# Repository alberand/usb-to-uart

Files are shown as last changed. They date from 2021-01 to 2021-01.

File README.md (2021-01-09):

# USB-C UART Converter based on CH330

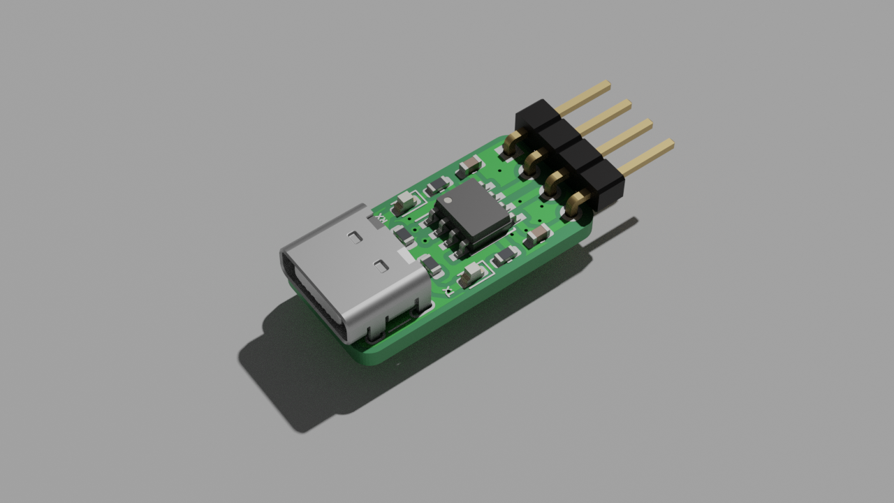
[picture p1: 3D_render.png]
3D Render of the board
[][2]

CH330 is crystal-less, <$0.35 USB UART converter in a SOIC-8 package. The CH330N
enumerates as CH340 or CH341 and its transfer speed goes up to ~2Mb/s.

Initially based on [Jan Henrik's prototype board][1]

## BOM

| Reference |  Value |  Mfr. Part |  Price |
| --- | --- | --- | --- |
| U1 | CH330N | CH330N | US$ 0.5518 |
| C2, C2 | 100n | CC0603KRX7R9BB104 | US$ 0.175 for 50 |
| D1, D2 | LED | 19-217/R6C-AL1M2VY/3T | US$ 0.282 for 20 |
| R1, R2 | 220 | 0603WAF2200T5E | US$ 0.12 for 100 |
| R3, R4 | 5.1k | 0603WAJ0512T5E | US$ 0.12 for 100 |
| P1 | USB_C_Plug_USB2.0 | U262-161N-4BVC11 | US$ 0.32 |
| J2 | | | |
| PCB | | | US$ 20 for 5 with shipping |

[1]: https://github.com/Jan--Henrik/CH330_Hardware
[2]: https://cloud.cadexchanger.com/app/viewer/5ff9c5427970d5002759ed40

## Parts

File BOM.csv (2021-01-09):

Reference | Value | Footprint | Datasheet | Mfr. Part
U1 | CH330N | Package_SO:SOIC-8_3.9x4.9mm_P1.27mm | https://datasheet.lcsc.com/szlcsc/2008191734_WCH-Jiangsu-Qin-Heng-CH330N_C108996.pdf | CH330N
C2 | 100n | Capacitor_SMD:C_0603_1608Metric | https://datasheet.lcsc.com/szlcsc/YAGEO-CC0603KRX7R9BB104_C14663.pdf | CC0603KRX7R9BB104
C1 | 100n | Capacitor_SMD:C_0603_1608Metric | https://datasheet.lcsc.com/szlcsc/YAGEO-CC0603KRX7R9BB104_C14663.pdf | CC0603KRX7R9BB104
D1 | LED | LED_SMD:LED_0603_1608Metric | https://datasheet.lcsc.com/szlcsc/Everlight-Elec-19-217-R6C-AL1M2VY-3T_C72044.pdf | 19-217/R6C-AL1M2VY/3T
R1 | 220 | Resistor_SMD:R_0603_1608Metric | https://datasheet.lcsc.com/szlcsc/Uniroyal-Elec-0603WAF2200T5E_C22962.pdf | 0603WAF2200T5E
R2 | 220 | Resistor_SMD:R_0603_1608Metric | https://datasheet.lcsc.com/szlcsc/Uniroyal-Elec-0603WAF2200T5E_C22962.pdf | 0603WAF2200T5E
J2 | Conn_01x04_Female | Connector_PinHeader_2.54mm:PinHeader_1x04_P2.54mm_Vertical | ~
P1 | USB_C_Plug_USB2.0 | Connector_USB:USB_C_Receptacle_XKB_U262-16XN-4BVC11 | https://datasheet.lcsc.com/szlcsc/2002271811_XKB-Connectivity-U262-161N-4BVC11_C319148.pdf | U262-161N-4BVC11
D2 | LED | LED_SMD:LED_0603_1608Metric | https://datasheet.lcsc.com/szlcsc/Everlight-Elec-19-217-R6C-AL1M2VY-3T_C72044.pdf | 19-217/R6C-AL1M2VY/3T
R3 | 5.1k | Resistor_SMD:R_0603_1608Metric | https://datasheet.lcsc.com/szlcsc/Uniroyal-Elec-0603WAJ0512T5E_C26000.pdf | 0603WAJ0512T5E
R4 | 5.1k | Resistor_SMD:R_0603_1608Metric | https://datasheet.lcsc.com/szlcsc/Uniroyal-Elec-0603WAJ0512T5E_C26000.pdf | 0603WAJ0512T5E

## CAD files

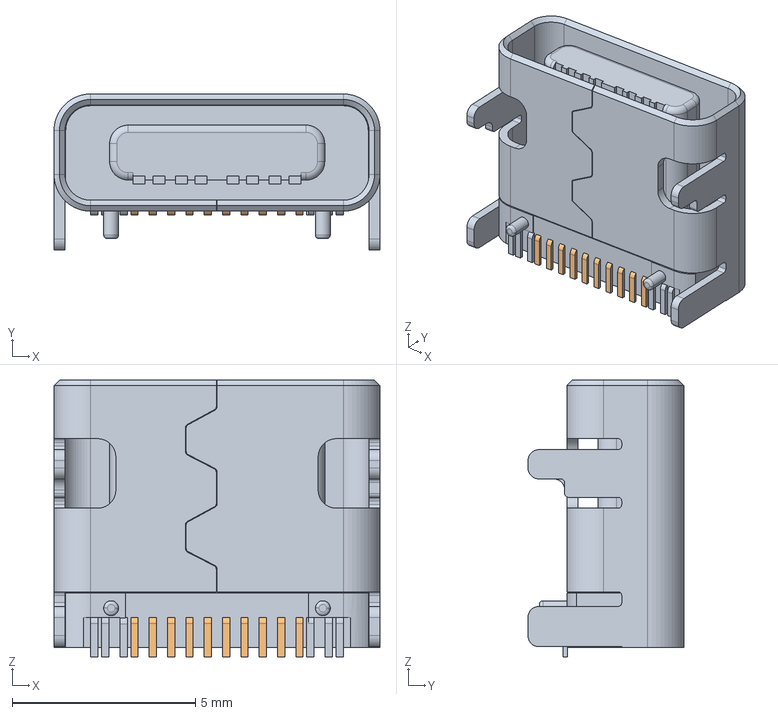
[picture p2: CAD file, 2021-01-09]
3dmodels/u262-16xn-4bvc11.stp
8.90 x 4.26 x 7.56 mm

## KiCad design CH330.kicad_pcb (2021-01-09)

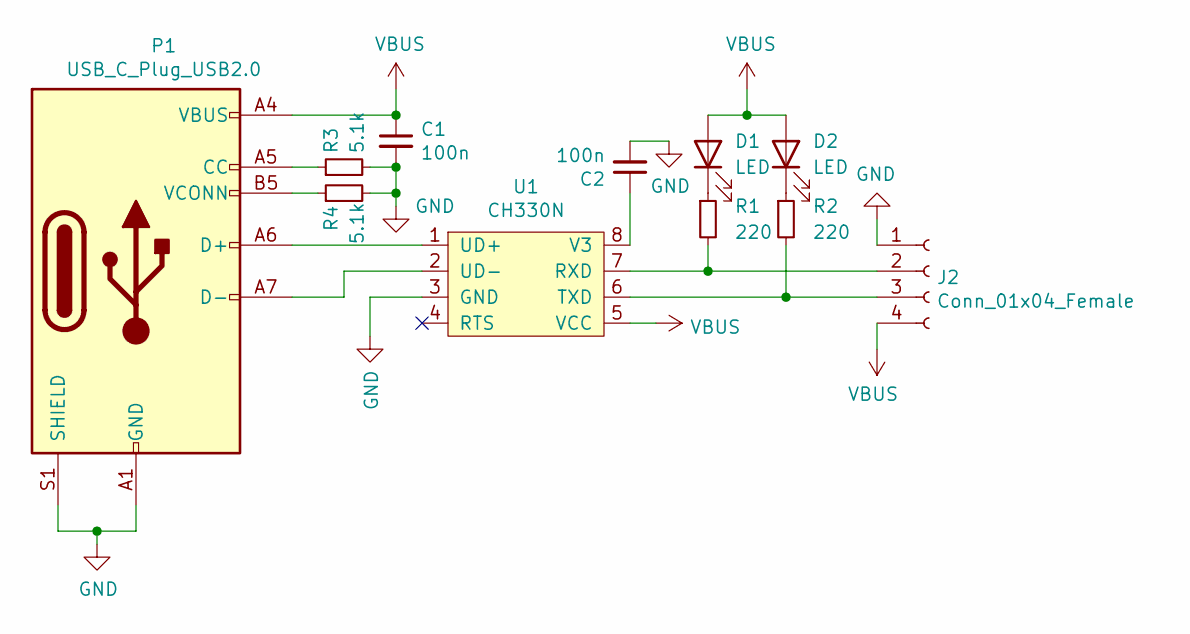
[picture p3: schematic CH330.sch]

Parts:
C1, C2: 100n; C_0603_1608Metric; Mfr. Part CC0603KRX7R9BB104
D1, D2: LED; LED_0603_1608Metric; Mfr. Part 19-217/R6C-AL1M2VY/3T
J2: Conn_01x04_Female; PinHeader_1x04_P2.54mm_Vertical
P1: USB_C_Plug_USB2.0; USB_C_Receptacle_XKB_U262-16XN-4BVC11; Mfr. Part U262-161N-4BVC11
R1, R2: 220; R_0603_1608Metric; Mfr. Part 0603WAF2200T5E
R3, R4: 5.1k; R_0603_1608Metric; Mfr. Part 0603WAJ0512T5E
U1: CH330N; SOIC-8_3.9x4.9mm_P1.27mm; Mfr. Part CH330N

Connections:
GND: C1.2, C2.2, J2.1, P1.A1 (GND), P1.A12 (GND), P1.B1 (GND), P1.B12 (GND), P1.S1 (SHIELD), R3.2, R4.2, U1.3 (GND)
unnamed: C2.1, U1.8 (V3)
unnamed: D1.1 (K), R1.1
unnamed: D2.1 (K), R2.1
unnamed: J2.2, R1.2, U1.7 (RXD)
unnamed: J2.3, R2.2, U1.6 (TXD)
unnamed: P1.A5 (CC), R3.1
unnamed: P1.A6 (D+), U1.1 (UD+)
unnamed: P1.A7 (D-), U1.2 (UD-)
unnamed: P1.B5 (VCONN), R4.1
VBUS: C1.1, D1.2 (A), D2.2 (A), J2.4, P1.A4 (VBUS), P1.A9 (VBUS), P1.B4 (VBUS), P1.B9 (VBUS), U1.5 (VCC)

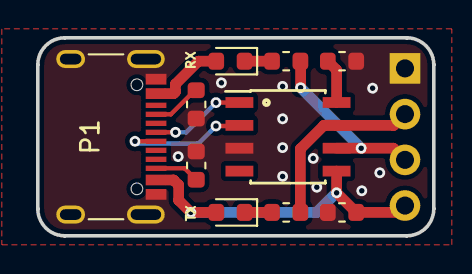
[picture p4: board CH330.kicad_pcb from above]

Board: 2 copper layers, 22.0 x 11.0 mm, 11 parts (0 on the bottom side), 11 nets.
